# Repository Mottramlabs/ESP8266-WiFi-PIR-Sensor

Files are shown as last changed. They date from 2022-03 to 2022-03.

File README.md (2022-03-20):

## ESP8266 Wi-Fi PIR - MLP201154
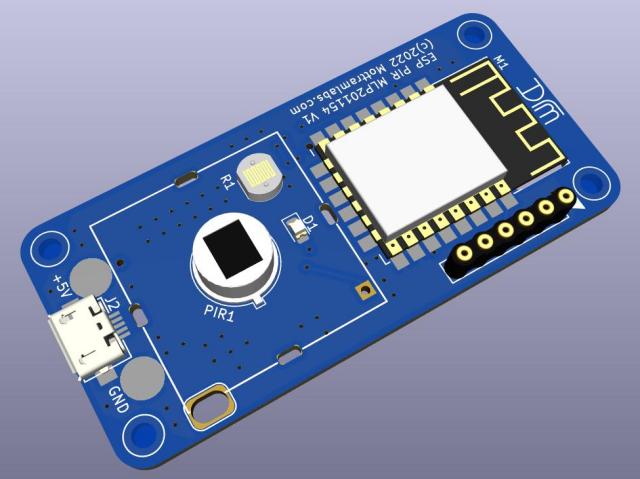
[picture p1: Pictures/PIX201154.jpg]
Display-Type-B


#### Description
A PIR motion sensor with onboard ESP8266 Wi-Fi module. This board design uses a 5V supply from a Micro USB connector therefore is not intended for battery or low power use, however this does mean it's always connected to the Wi-Fi and so responses quickly. This makes the board ideal as a room occupancy sensor or if the case design is waterproof it could be used out doors.

>**Range** 
The range of the sensor depends on the Lens used. The small cap style lens (clips onto the sensor) are good for short range detection ideal for proximity sensing. The larger lens (23.5mmx23.5mm) are good for room sensing and and have a range of around 10m depending on ambient temperature. 

The board includes a status LED  mounted under the larger PIR lens along with a light sensor. This makes it easier to design a waterproof case, however the LED should be turned off before sampling the light level else the readings maybe inaccurate.

Programming the board is done via an external USB to serial interface, a 6 pin header on the board provides the connections required, RX TX GPIO0 and Reset.

### Features
- 5V supply (Micro USB or solder pads), with reverse polarity protection
- Status LED Controlled By The ESP8266
- Light Level Sensor (Connected to A0)
- PIR Sensor Used: AM612

### Firmware
Sample code is provided for basic board testing, a simple Wi-Fi demo with access point and an MQTT application.

### More info
https://www.mottramlabs.com/

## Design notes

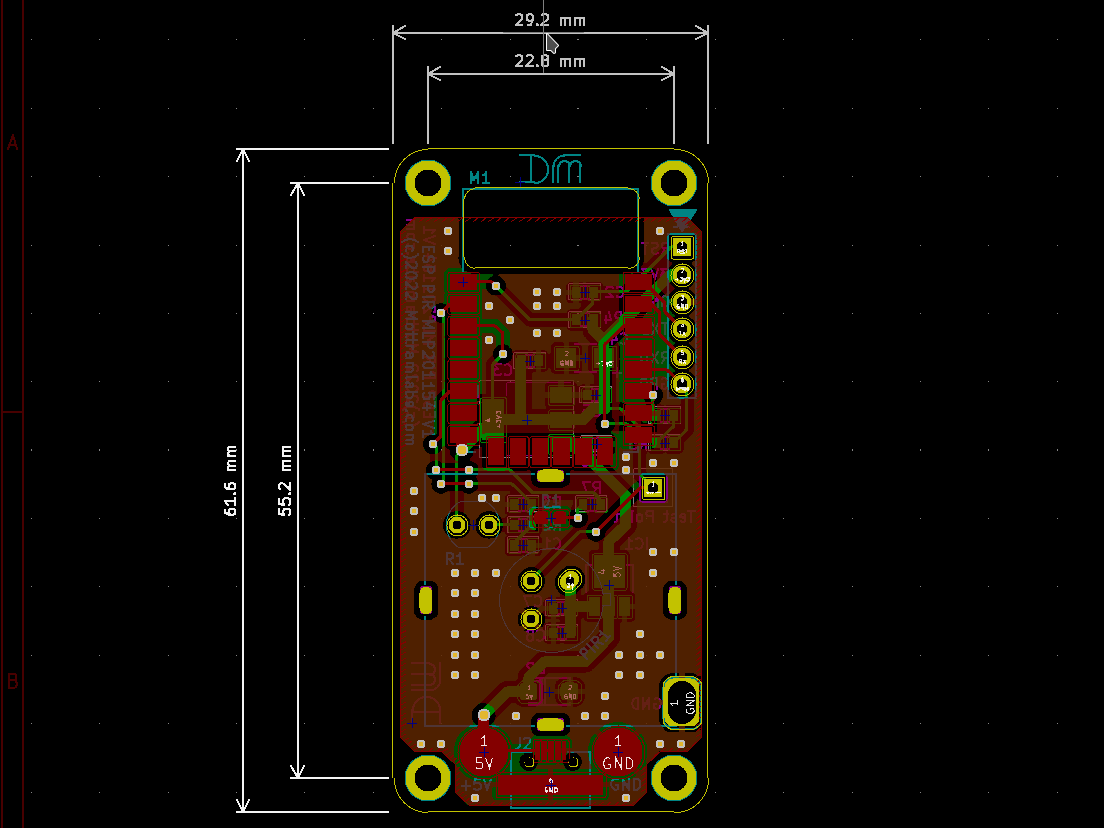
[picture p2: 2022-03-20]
Pictures/Dims.png

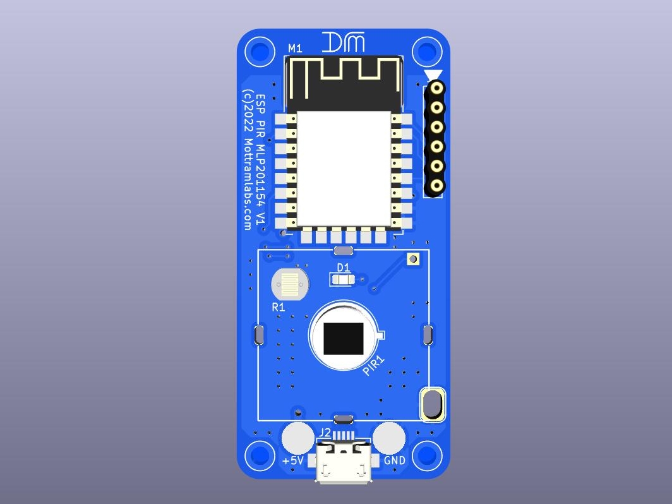
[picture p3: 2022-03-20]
PCB Layout/Top View.jpg

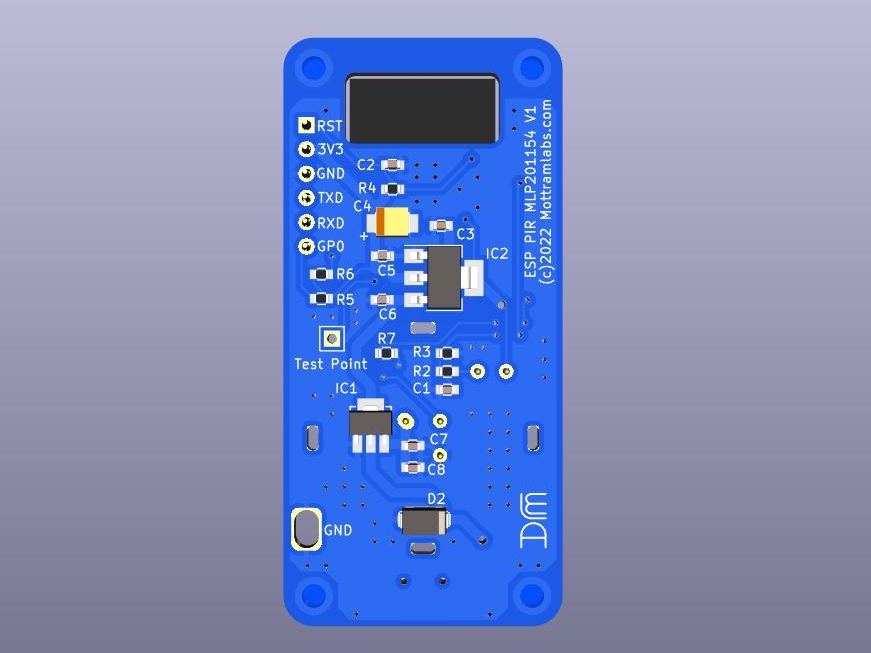
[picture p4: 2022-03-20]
PCB Layout/Bottom View.jpg

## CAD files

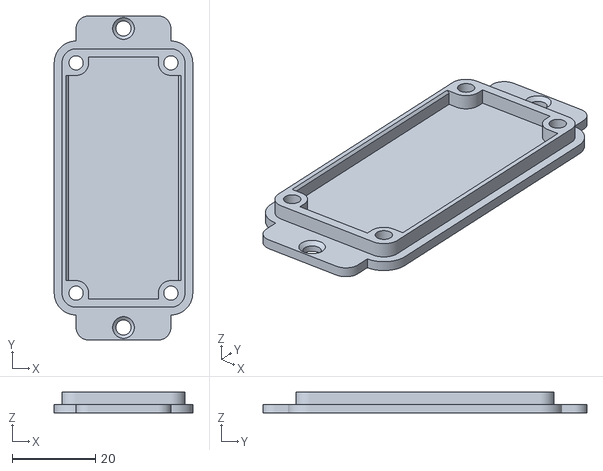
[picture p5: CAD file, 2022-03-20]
3D Printed Case/PIR Back.stl
33.2 x 77.8 x 5.00

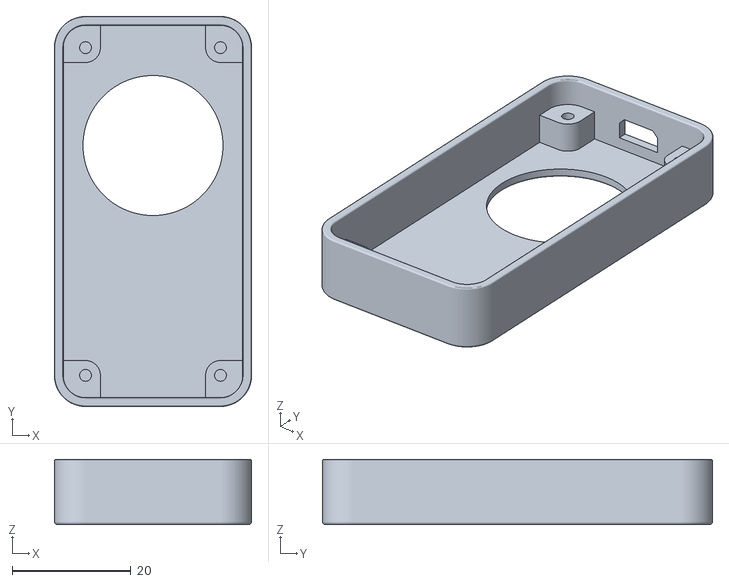
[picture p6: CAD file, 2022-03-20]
3D Printed Case/PIR Front.stl
33.2 x 65.8 x 11.0

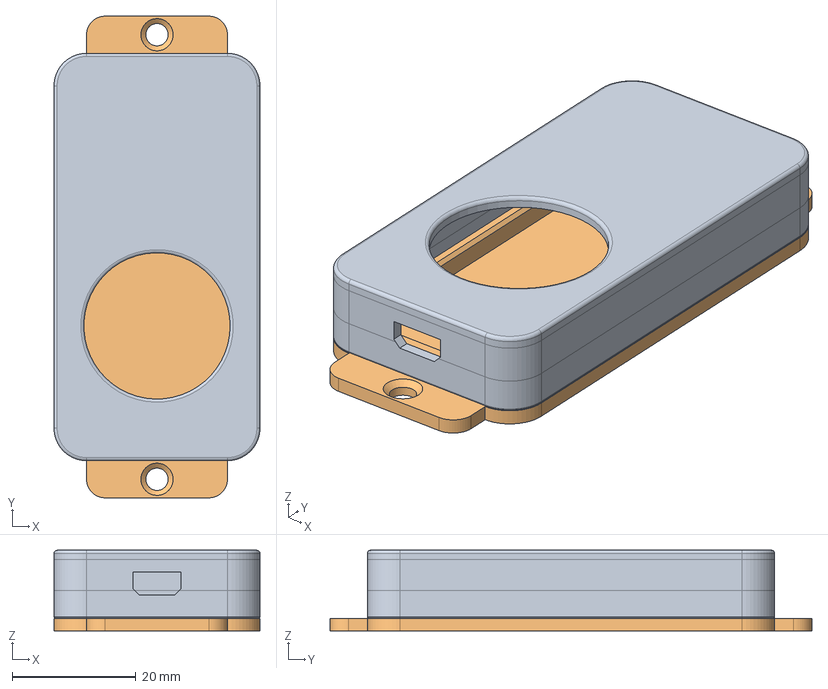
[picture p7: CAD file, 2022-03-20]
3D Printed Case/PIR Case V1.FCStd
33.2 x 77.8 x 13.0 mm
Front Section
Rear Panel

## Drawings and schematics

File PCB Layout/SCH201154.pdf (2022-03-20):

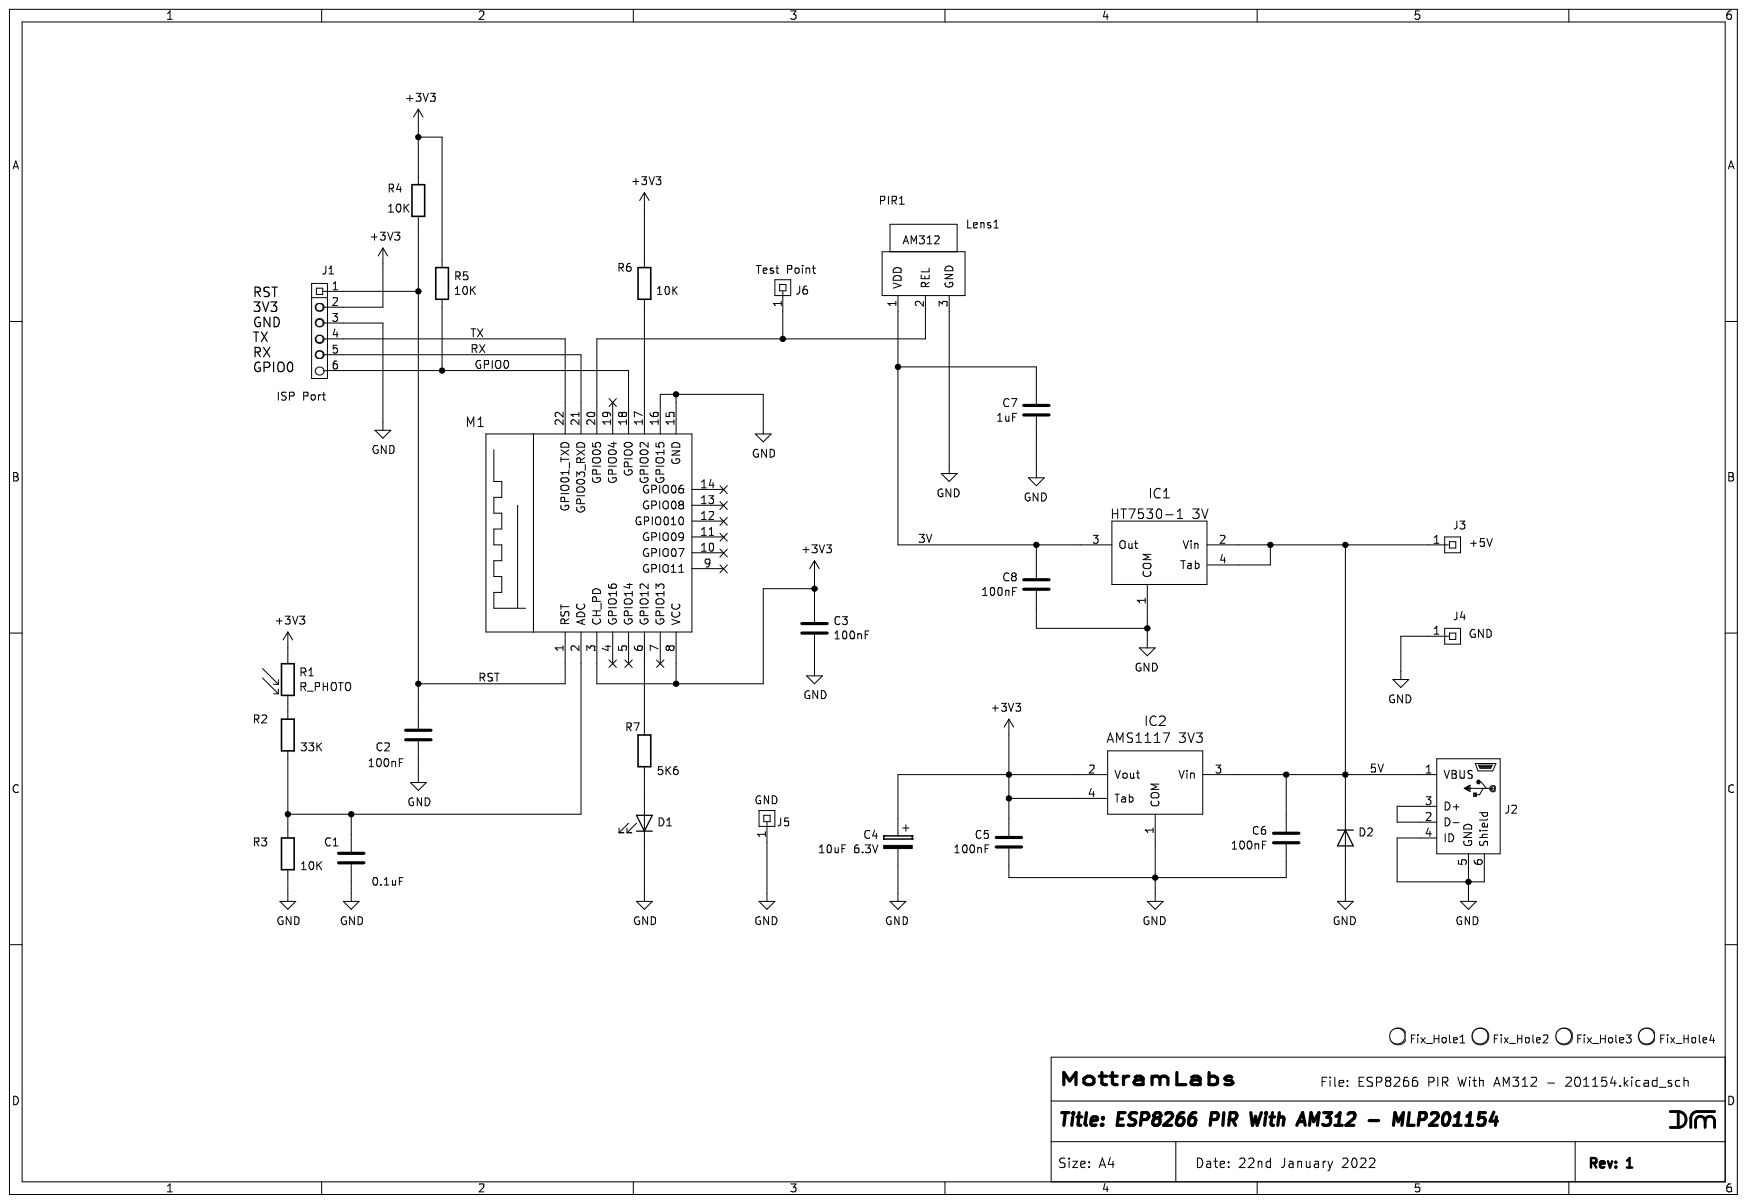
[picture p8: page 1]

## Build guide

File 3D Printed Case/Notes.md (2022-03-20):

A simple 3D case designed using **Freecad**

The case is screwed together using 4off 8mm long No.4 (2.9mm)

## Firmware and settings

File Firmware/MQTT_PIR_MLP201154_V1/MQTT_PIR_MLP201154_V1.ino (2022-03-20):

/*
    Title:        MQTT PIR Sensor - MLP201154
    Date:         12th February 2022
    Version:      1
    Description:  Sample code
    Device:       ESP8266
    Notes:        Sends events via MQTT, on motion and also when the PIR sensor is cleared. Adds raw A/D value from light sensor
    WiFi:         See "WiFi_Settings.h" for wifi AP and password
    MQTT:         See "MQTT_Settings.h" for MQTT broker and topic
*/

/* ********************************** Compiler settings, un-comment to use ************************** */
//#define Fixed_IP                      // un-comment to use a fixed IP address to speed up development
//#ifdef Watchdog_ON                    // watchdog items, comment out if not used
//#define Print_Report_Level_1          // un-comment for option
#define Print_Report_Level_2          // un-comment for option, report received MQTT message
#define Print_Report_Level_3          // un-comment for option
/* ************************************************************************************************** */

#include <ESP8266WiFi.h>              // needed for EPS8266
#include <WiFiClient.h>               // WiFi client

// custom settings files
#include "Wifi_Settings.h"            // custom Wifi settings
#include "MQTT_Settings.h"            // MQTT broker and topic
#include "Project_Settings.h"         // board specific details.

// incude WiFi and MQTT functions
WiFiClient espClient;                 // for ESP8266 boards
#include <PubSubClient.h>             // http://pubsubclient.knolleary.net/api.html
PubSubClient client(espClient);       // ESP pubsub client
#include "WiFi_Functions.h"           // read wifi data
#include "MQTT_Functions.h"           // MQTT Functions


void setup() {

  Serial.begin(115200); Serial.println(""); Serial.println(""); Serial.println("Up and Clackin!");
  Serial.println(__FILE__);

  // I/O
  pinMode(LED, OUTPUT);
  pinMode(PIR, INPUT);

  // connect to WiFi access point
  Get_Wifi();

  // connect to the MQTT broker
  client.setServer(mqtt_server, 1883);
  client.setCallback(callback);

  // reset heartbeat timer
  LastMsg = millis();

} // end of setup


void loop() {

  if (!client.connected()) {
    reconnect();
  } // end if
  client.loop();

  // LED off
  if (millis() - LastMsg > LED_ON_Time) {
    digitalWrite(LED, LOW);
  } // end if

  // test PIR
  if (digitalRead(PIR) == HIGH) {

    if (PIR_Flag == false) {
      PIR_Flag = true;
      PIR_Status = "Event";
      Report_Request = 1;

      // LED on timer      
      LED_Timer = LastMsg = millis();
      digitalWrite(LED, HIGH);
    } // end if

    else {
      PIR_Status = "High";
    } // end else

  } // end if

  // PIR is low
  else {

    if (PIR_Flag == true) {
      PIR_Flag = false;
      PIR_Status = "Low";
      Report_Request = 1;
    } // end if

  } // end else


  // headbeat or report requested
  if (millis() - LastMsg > Heatbeat || Report_Request == 1) {

    LastMsg = millis();
    Report_Request = 0;

    // update event progress counter
    ++Heart_Value;
    if (Heart_Value > Heartbeat_Range) {
      Heart_Value = 1;
    } // end if

    // heartbeat timed out or report message requested

    // sample light level. don't do if new event as the LED maybe cause an error
    if (PIR_Status != "Event") {
      Light_Level = analogRead(A0);
    } // end if


    // get a report make and make as an array
    String Report = Status_Report();
    char Report_array[(Report.length() + 1)];
    Report.toCharArray(Report_array, (Report.length() + 1));

#ifdef Print_Report_Level_2
    // display a report when publishing
    Serial.print("Published To topic: "); Serial.print(InStatus); Serial.print("  -  Report Sent: "); Serial.println(Report_array);
#endif
    // send a status report
    client.publish(InStatus, Report_array);

  } // end of heartbeat timer

} // end of loop

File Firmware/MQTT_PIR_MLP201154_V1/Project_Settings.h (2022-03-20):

/*
    variables and functions used by this project
*/

// Heatbeat items
#define Heartbeat_Range   99                      // event count max value
#define Heatbeat    10000                         // heartbeat timer value, in mS

// Watchdog items
volatile int Watchdog_Timout = 1200;              // time in seconds before watchdog times out, 1200 = 1200 seconds or 20 minutes

// Heatbeat timer
int Heart_Value = 0;                              // timer
long LastMsg = 0;                                 // message sent counter

// Custom default values
String WiFi_SSID = "None";                        // SSID string
String My_MAC = "";                               // MAC address, tobe read from ESP8266
char MAC_array[13] = "000000000000";              // MAC definition
String My_IP = "";                                // IP address

volatile int Report_Request = 0;                  // set to 1 if report required

// ********************************************************************************************************
// ************************ project specific variables ****************************************************
// ********************************************************************************************************

#define LED 12
#define PIR 5
int PIR_Flag = false;
String PIR_Status = "Boot";
int Light_Level = 0;

unsigned long LED_Timer = 0;
#define LED_ON_Time 100

// ********************************************************************************************************
// ************************ watchdog items ****************************************************************
// ********************************************************************************************************


#include <Ticker.h>
Ticker secondTick;
volatile int watchdogCount = 0;

// watchdog timer function, watchdog is clear when the ststus report is requested by a GET request
void ISRwatchdog() {
  watchdogCount++;
  if (watchdogCount == Watchdog_Timout) {
    Serial.println();
    Serial.println("The watchdog bites !!!!!");
    ESP.reset();
  } // end of timeout test
} // end of watchdog count
